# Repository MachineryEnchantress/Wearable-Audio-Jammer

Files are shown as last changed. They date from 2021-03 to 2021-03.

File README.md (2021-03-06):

# Naomi Wu's Wearable Audio Jammer
A Cyberpunk choker based on the University of Chicago, SAND Labs work:

https://sandlab.cs.uchicago.edu/jammer/

https://github.com/y-x-c/wearable-microphone-jamming

Video here:

Naomi Wu looking cyberpunk with her wearable microphone jammer on the streets of Shenzhen China. (http://www.youtube.com/watch?v=H1rozZ7ebxQ "Cyberpunk Ultrasonic Microphone Jammer")

Many thanks to JLCPCB for their sponsorship and assistance.

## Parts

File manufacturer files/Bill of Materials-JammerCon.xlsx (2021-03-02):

Designator | Comment | Value | Manufacturer Part Number 1 | Footprint | Manufacturer 1 | Quantity |  | taobao_price | Sourcing from taobao
B1, B2 | Header 9 |  |  | HDR1X9 |  | 2 |  | 0.17 | https://item.taobao.com/item.htm?spm=a1z09.2.0.0.78312e8d1CtAot&id=43937573926&_u=32085775663e15
B3, B4, B5, B6, B7, B8, B9, B10, B11 | Header 6 |  |  | HDR1X6 |  | 9 |  | 0.17 | https://item.taobao.com/item.htm?spm=a1z09.2.0.0.78312e8d1CtAot&id=43937573926&_u=32085775663e15
C2 | Cap | 22uF |  | C0805 |  | 1 |  | 0.08 | https://item.taobao.com/item.htm?spm=a1z10.3-c-s.w4002-23029579464.9.41df4181djI5tA&id=583167630909
C5 | Cap | 10uF |  | C0805 |  | 1 | https://octopart-clicks.com/click/altium?sku=490-16824-1-ND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 | 0.06 | https://item.taobao.com/item.htm?spm=a1z10.3-c-s.w4002-23029579464.9.41df4181djI5tA&id=583167630909
C7 | Cap | 100nF |  | C0603 |  | 1 | https://octopart-clicks.com/click/altium?sku=311-1341-1-ND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 | 0.03 | https://item.taobao.com/item.htm?spm=a1z10.3-c-s.w4002-23029579464.9.41df4181djI5tA&id=583167630909
C8 | Cap | 47nF |  | C0603 |  | 1 | https://octopart-clicks.com/click/altium?sku=399-7929-1-ND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 | 0.43 | https://item.taobao.com/item.htm?spm=a1z10.3-c-s.w4002-23029579464.9.41df4181djI5tA&id=583167630909
C10 | Cap | 33nF |  | C0603 |  | 1 | https://octopart-clicks.com/click/altium?sku=399-7904-1-ND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 | 0.45 | https://detail.tmall.com/item.htm?id=41231814882&cm_id=140105335569ed55e27b&abbucket=1&skuId=3984688435812
C14 | Cap | 20pF |  | C0402 |  | 1 |  | 0.025 | https://detail.tmall.com/item.htm?id=41231814882&cm_id=140105335569ed55e27b&abbucket=1&skuId=3984688435812
C15, C20 | Cap | 10uF |  | C0805 |  | 2 |  | 0.15 | https://detail.tmall.com/item.htm?id=41231814882&cm_id=140105335569ed55e27b&abbucket=1&skuId=3984688435812
C16 | Cap | 22uF |  | C0603 |  | 1 |  | 0.1 | https://detail.tmall.com/item.htm?id=41231814882&cm_id=140105335569ed55e27b&abbucket=1&skuId=3984688435812
C17, C21, C26, C36, C39, C41, C42 | Cap | 100nF |  | R0402 |  | 7 |  | 0.047 | https://detail.tmall.com/item.htm?id=41231814882&cm_id=140105335569ed55e27b&abbucket=1&skuId=3984688435812
C18 | Cap | 10nF |  | R0402 |  | 1 |  | 0.078 | https://detail.tmall.com/item.htm?id=41231814882&cm_id=140105335569ed55e27b&abbucket=1&skuId=3984688435812
C19 | Cap | 10uF |  | C0402 |  | 1 |  | 0.06 | https://detail.tmall.com/item.htm?id=41231814882&cm_id=140105335569ed55e27b&abbucket=1&skuId=3984688435812
C22, C24 | Cap | 10uF |  | C0603 |  | 2 |  | 0.12 | https://detail.tmall.com/item.htm?id=41231814882&cm_id=140105335569ed55e27b&abbucket=1&skuId=3984688435812
C23, C25 | Cap | 1uF |  | C0603 |  | 2 |  | 0.08 | https://detail.tmall.com/item.htm?id=41231814882&cm_id=140105335569ed55e27b&abbucket=1&skuId=3984688435812
C27, C28 | Cap | 220nF |  | C0603 |  | 2 |  | 0.06 | https://detail.tmall.com/item.htm?id=41231814882&cm_id=140105335569ed55e27b&abbucket=1&skuId=3984688435812
C29 | Cap | 1uF |  | R0402 |  | 1 |  | 0.06 | https://detail.tmall.com/item.htm?id=41231814882&cm_id=140105335569ed55e27b&abbucket=1&skuId=3984688435812
C34, C35 | Cap | 100nF |  | C0201 |  | 2 |  | 0.04 | https://detail.tmall.com/item.htm?id=567737110271&ns=1&abbucket=1&skuId=3788055905276
C37, C38, C43, C44 | Cap | 22pF |  | C0402 |  | 4 |  | 0.06 | https://detail.tmall.com/item.htm?id=567737110271&ns=1&abbucket=1&skuId=3788055905276
C40 | Cap | 1uF |  | C0402 |  | 1 |  | 0.06 | https://detail.tmall.com/item.htm?id=567737110271&ns=1&abbucket=1&skuId=3788055905276
D1 | MBRA340T3G |  | MBRA340T3G (https://octopart-clicks.com/click/altium?sku=MBRA340T3GOSCT-ND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) | MBRA340T3G | ON Semiconductor (https://octopart-clicks.com/click/altium?sku=MBRA340T3GOSCT-ND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) | 1 | https://octopart-clicks.com/click/altium?sku=MBRA340T3GOSCT-ND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 | 2.55 | https://detail.tmall.com/item.htm?spm=a230r.1.14.23.564d789axD7T8J&id=529444947039&ns=1&abbucket=1
D4 | MBR120VLSFT3G |  | MBR120VLSFT3G (https://octopart-clicks.com/click/altium?manufacturer=ON%20Semiconductor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) | SOD-123FL | ON Semiconductor (https://octopart-clicks.com/click/altium?manufacturer=ON%20Semiconductor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) | 1 | https://octopart-clicks.com/click/altium?manufacturer=ON%20Semiconductor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 | 3 | https://detail.tmall.com/item.htm?spm=a230r.1.14.7.21cf193buPHXgb&id=576040918117&ns=1&abbucket=1
J1 | MICRO USB MK5P |  |  | 1050170001 |  | 1 |  | 2.1 | https://detail.tmall.com/item.htm?id=21097776848&ns=1&abbucket=1&skuId=4415526175357
L1 | BMB2A0430RS2 |  | BK1608HW431-T (https://octopart-clicks.com/click/altium?sku=587-1878-1-ND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) | L0603 | Taiyo Yuden (https://octopart-clicks.com/click/altium?sku=587-1878-1-ND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) | 1 | https://octopart-clicks.com/click/altium?sku=587-1878-1-ND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 | 0.3 | https://detail.tmall.com/item.htm?id=572996827266
L3 | BLM21 |  |  | *BEADC2012X87N |  | 1 |  | 0.04 | https://item.taobao.com/item.htm?id=543681503837&ns=1&abbucket=1
L4 | Inductor | 22uH | CDRH105RNP-220NC (https://octopart-clicks.com/click/altium?sku=308-2173-1-ND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) | CDRH105RNP-220NC | Sumida (https://octopart-clicks.com/click/altium?sku=308-2173-1-ND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) | 1 | https://octopart-clicks.com/click/altium?sku=308-2173-1-ND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 | 12.5 | https://detail.tmall.com/item.htm?spm=a230r.1.14.1.379e24aaUpzAhD&id=584273759003&ns=1&abbucket=1
LED1 | RED Indicator |  | XZMDK68W-2 (https://octopart-clicks.com/click/altium?sku=1497-1174-1-ND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) | LED-0402-RED | SunLED (https://octopart-clicks.com/click/altium?sku=1497-1174-1-ND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) | 1 | https://octopart-clicks.com/click/altium?sku=1497-1174-1-ND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 | 1.06 | https://detail.tmall.com/item.htm?id=572996827266
LS1, LS2, LS3, LS4, LS5, LS6, LS7, LS8, LS9, LS10, LS11, LS12, LS13, LS14, LS15, LS16, LS17, LS18, LS19, LS20, LS21, LS22, LS23, LS24 | Ultrasonic tranducer |  |  | ULTRASONICSENSOR |  | 24 |  | 5 | https://item.taobao.com/item.htm?spm=a1z09.2.0.0.5d512e8dT8jIOL&id=574912876524&_u=32085775662157
P22 | SMT Battery connector |  | 0781710002 (https://octopart-clicks.com/click/altium?sku=WM4459CT-ND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) | CONN_MOLEX_781710002 | Molex (https://octopart-clicks.com/click/altium?sku=WM4459CT-ND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) | 1 | https://octopart-clicks.com/click/altium?sku=WM4459CT-ND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 | 1 | https://item.taobao.com/item.htm?id=589091209439&ns=1&abbucket=1
Q1, Q4 | DMG2305UX-13 |  | DMG2305UX-13 (https://octopart-clicks.com/click/altium?sku=DMG2305UX-13DICT-ND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) | SOT23-3 | Diodes (https://octopart-clicks.com/click/altium?sku=DMG2305UX-13DICT-ND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) | 2 | https://octopart-clicks.com/click/altium?sku=DMG2305UX-13DICT-ND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 | 0.8 | https://item.taobao.com/item.htm?id=566110520596&ns=1&abbucket=1
R1, R7 | Res3 | 10k |  | R0402 | Yageo (https://octopart-clicks.com/click/altium?sku=311-10KJRCT-ND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) | 2 | https://octopart-clicks.com/click/altium?sku=311-10KJRCT-ND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 | 0.033 | https://detail.tmall.com/item.htm?id=575811920221&ns=1&abbucket=1&skuId=3955476259496
R2 | Res4 | 100k |  | R0402 | Yageo (https://octopart-clicks.com/click/altium?sku=311-100KLRCT-ND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) | 1 | https://octopart-clicks.com/click/altium?sku=311-100KLRCT-ND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 | 0.0331 | https://detail.tmall.com/item.htm?id=575811920221&ns=1&abbucket=1&skuId=3955476259496
R3 | Res5 | 30k |  | R0603 | Loading... (https://octopart-clicks.com/click/altium?sku=2019-RN731JTTD6902F50TR-ND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) | 1 | https://octopart-clicks.com/click/altium?sku=2019-RN731JTTD6902F50TR-ND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 | 0.0331 | https://detail.tmall.com/item.htm?id=575811920221&ns=1&abbucket=1&skuId=3955476259496
R4 | Res6 | 143k |  | R0603 | Stackpole Electronics (https://octopart-clicks.com/click/altium?manufacturer=Stackpole%20Electronics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) | 1 | https://octopart-clicks.com/click/altium?manufacturer=Stackpole%20Electronics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 | 0.025 | https://detail.tmall.com/item.htm?id=625814257700&ns=1&abbucket=1&skuId=4438099333339
R5 | Res7 | 10k |  | R0603 | NEOHM - TE CONNECTIVITY (https://octopart-clicks.com/click/altium?manufacturer=NEOHM%20-%20TE%20CONNECTIVITY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) | 1 | https://octopart-clicks.com/click/altium?manufacturer=NEOHM%20-%20TE%20CONNECTIVITY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 | 0.03 | https://detail.tmall.com/item.htm?id=625814257700&ns=1&abbucket=1&skuId=4438099333339
R6 | Res8 | 3.09k |  | R0603 | Yageo (https://octopart-clicks.com/click/altium?sku=311-3.09KHRCT-ND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) | 1 | https://octopart-clicks.com/click/altium?sku=311-3.09KHRCT-ND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 | 0.025 | https://detail.tmall.com/item.htm?id=625814257700&ns=1&abbucket=1&skuId=4438099333339
R21, R22, R23 | Res9 | 1k |  | R0402 |  | 3 |  | 0.031 | https://detail.tmall.com/item.htm?id=575811920221&ns=1&abbucket=1&skuId=3955476259496
R24, R25, R34, R35 | Res10 | 10k |  | R0402 |  | 4 |  | 0.0331 | https://detail.tmall.com/item.htm?id=575811920221&ns=1&abbucket=1&skuId=3955476259496
R26, R27 | Res11 | 22R |  | R0402 |  | 2 |  | 0.0331 | https://detail.tmall.com/item.htm?id=575811920221&ns=1&abbucket=1&skuId=3955476259496
R28 | Res12 | 10 |  | R0402 |  | 1 |  | 0.0331 | https://detail.tmall.com/item.htm?id=575811920221&ns=1&abbucket=1&skuId=3955476259496
R29, R30 | Res13 | 10k |  | R0603 |  | 2 |  | 0.03 | https://detail.tmall.com/item.htm?id=625814257700&ns=1&abbucket=1&skuId=4438099333339
R33 | Res14 | 100k |  | R0402 |  | 1 |  | 0.0331 | https://detail.tmall.com/item.htm?id=575811920221&ns=1&abbucket=1&skuId=3955476259496
R36 | Res15 | 1k |  | R0402 |  | 1 |  | 0.031 | https://detail.tmall.com/item.htm?id=575811920221&ns=1&abbucket=1&skuId=3955476259496
R37, R38 | Res16 | 10k |  | R0201 |  | 2 |  | 0.04 | https://detail.tmall.com/item.htm?id=627633904387&cm_id=140105335569ed55e27b&abbucket=1
SW1 | TL2201EEZB |  |  | TL2201EEZB |  | 1 |  | 1.1 | https://detail.tmall.com/item.htm?spm=a230r.1.14.66.68154c60uAgV0h&id=629072861735&ns=1&abbucket=1
U1 | TPS61175PWPR |  | TPS61175PWPR (https://octopart-clicks.com/click/altium?sku=296-24013-1-ND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) | TPS61175PWPR | Texas Instruments (https://octopart-clicks.com/click/altium?sku=296-24013-1-ND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) | 1 | https://octopart-clicks.com/click/altium?sku=296-24013-1-ND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 | 2 | https://item.taobao.com/item.htm?id=612864318239&ns=1&abbucket=1
U5 | ATMEGA328P-A |  | ATMEGA328PB-AUR (https://octopart-clicks.com/click/altium?manufacturer=Microchip%20%2F%20Atmel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) | ATMEGA328P | Microchip / Atmel (https://octopart-clicks.com/click/altium?manufacturer=Microchip%20%2F%20Atmel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) | 1 | https://octopart-clicks.com/click/altium?manufacturer=Microchip%20%2F%20Atmel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 | 7.2 | https://item.taobao.com/item.htm?id=636596676424&ns=1&abbucket=1
U7 | MCP73831T-2ACI/OT |  | MCP73831T-2ACI/OT (https://octopart-clicks.com/click/altium?manufacturer=Microchip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) | SOT23-5 | Microchip (https://octopart-clicks.com/click/altium?manufacturer=Microchip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) | 1 | https://octopart-clicks.com/click/altium?manufacturer=Microchip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 | 2.5 | https://item.taobao.com/item.htm?id=634780881501&ns=1&abbucket=1
U8 | AD9833BRMZ-REEL7 |  |  | SOP50P490X110-10N |  | 1 |  | 9 | https://item.taobao.com/item.htm?id=635505137376&ns=1&abbucket=1
U9 | PAM8403DR |  |  | SOIC127P605X175-16N |  | 1 |  | 0.85 | https://item.taobao.com/item.htm?id=608059829639&ns=1&abbucket=1
U11 | ATMEGA16U2-MU |  |  | *QFN50P500X500X100-33N |  | 1 |  | 13 | https://item.taobao.com/item.htm?id=622633930047&ns=1&abbucket=1
Y1 | 25MHz |  | ECS-3951M-250-BN-TR (https://octopart-clicks.com/click/altium?sku=XC321CT-ND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) | OSC_ECS-3951M-250-BN-TR | ECS International (https://octopart-clicks.com/click/altium?sku=XC321CT-ND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) | 1 | https://octopart-clicks.com/click/altium?sku=XC321CT-ND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 | 1.5 | https://item.taobao.com/item.htm?id=596798388613&ali_trackid=1_60a99f19a8de875dff8d5a230e91020d
Y3, Y4 | 16MHz | 16MHz |  | BT-XTAL_2016_N |  | 2 |  | 1.7 | https://item.taobao.com/item.htm?id=596798388613&ali_trackid=1_60a99f19a8de875dff8d5a230e91020d
Z3, Z4 | VARISTOR_0603 |  |  | *R0603 |  | 2 |  | 1.1 | https://detail.tmall.com/item.htm?spm=a230r.1.14.8.2f1137ddH6zNkv&id=629202685810&ns=1&abbucket=1
D5, D6 | Do not place |  |  |  | ON Semiconductor / Fairchild (https://octopart-clicks.com/click/altium?manufacturer=ON%20Semiconductor%20%2F%20Fairchild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) | 2
P23 | Do not place |  |  | HDR1X2 |  | 1
P24 | Do not place |  |  | HDR1X2 |  | 1
P25, P26 | Do not place |  |  | TC2030-MCP |  | 2

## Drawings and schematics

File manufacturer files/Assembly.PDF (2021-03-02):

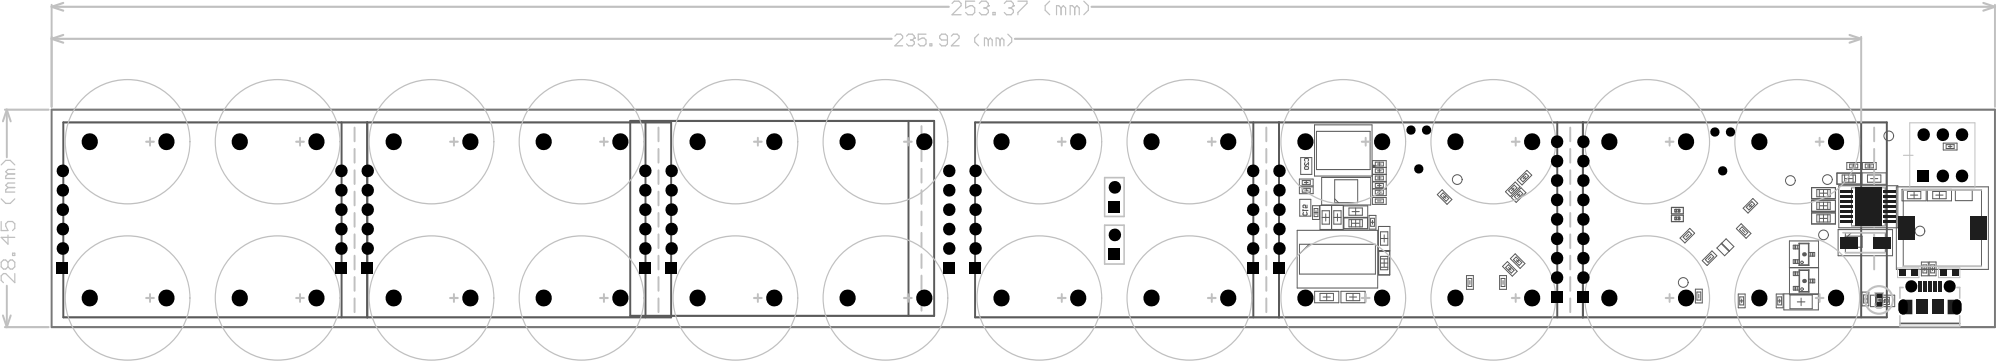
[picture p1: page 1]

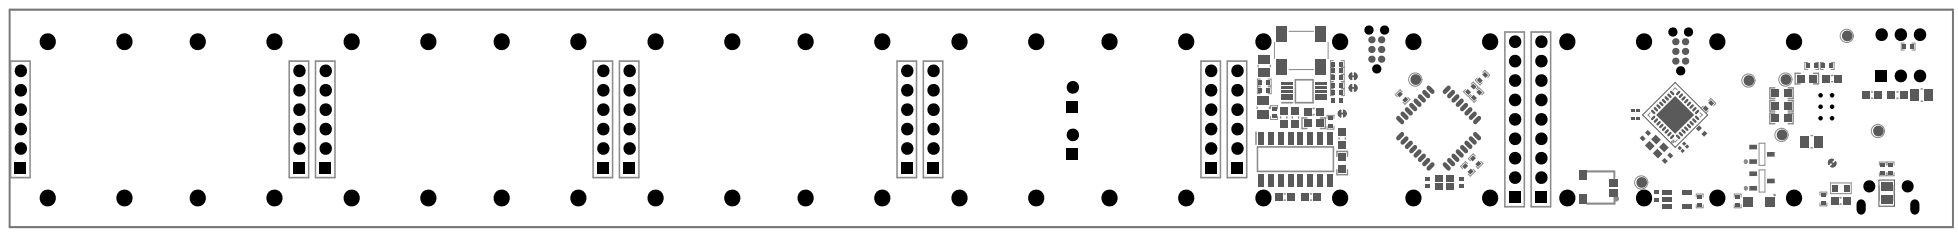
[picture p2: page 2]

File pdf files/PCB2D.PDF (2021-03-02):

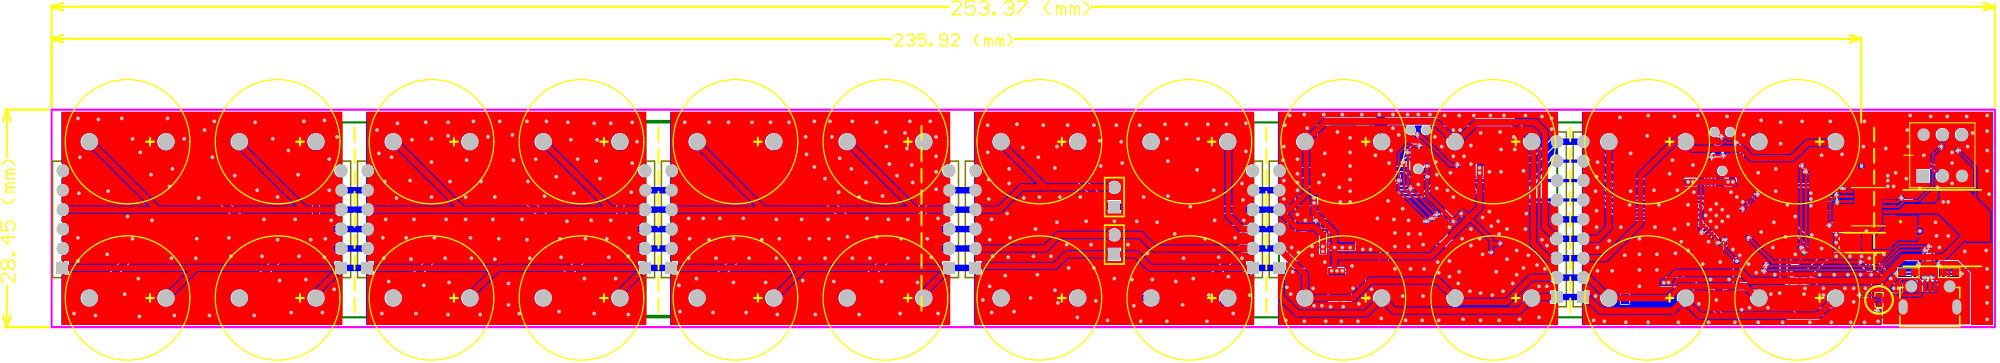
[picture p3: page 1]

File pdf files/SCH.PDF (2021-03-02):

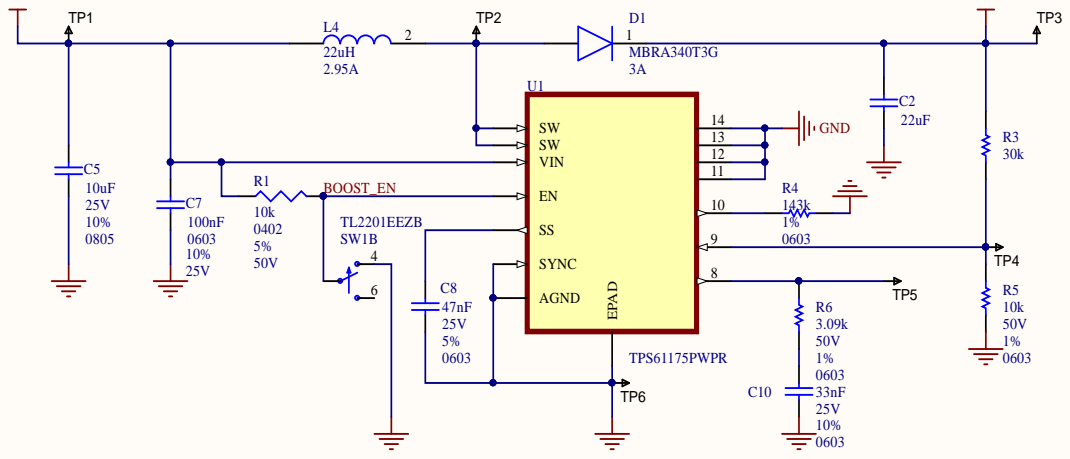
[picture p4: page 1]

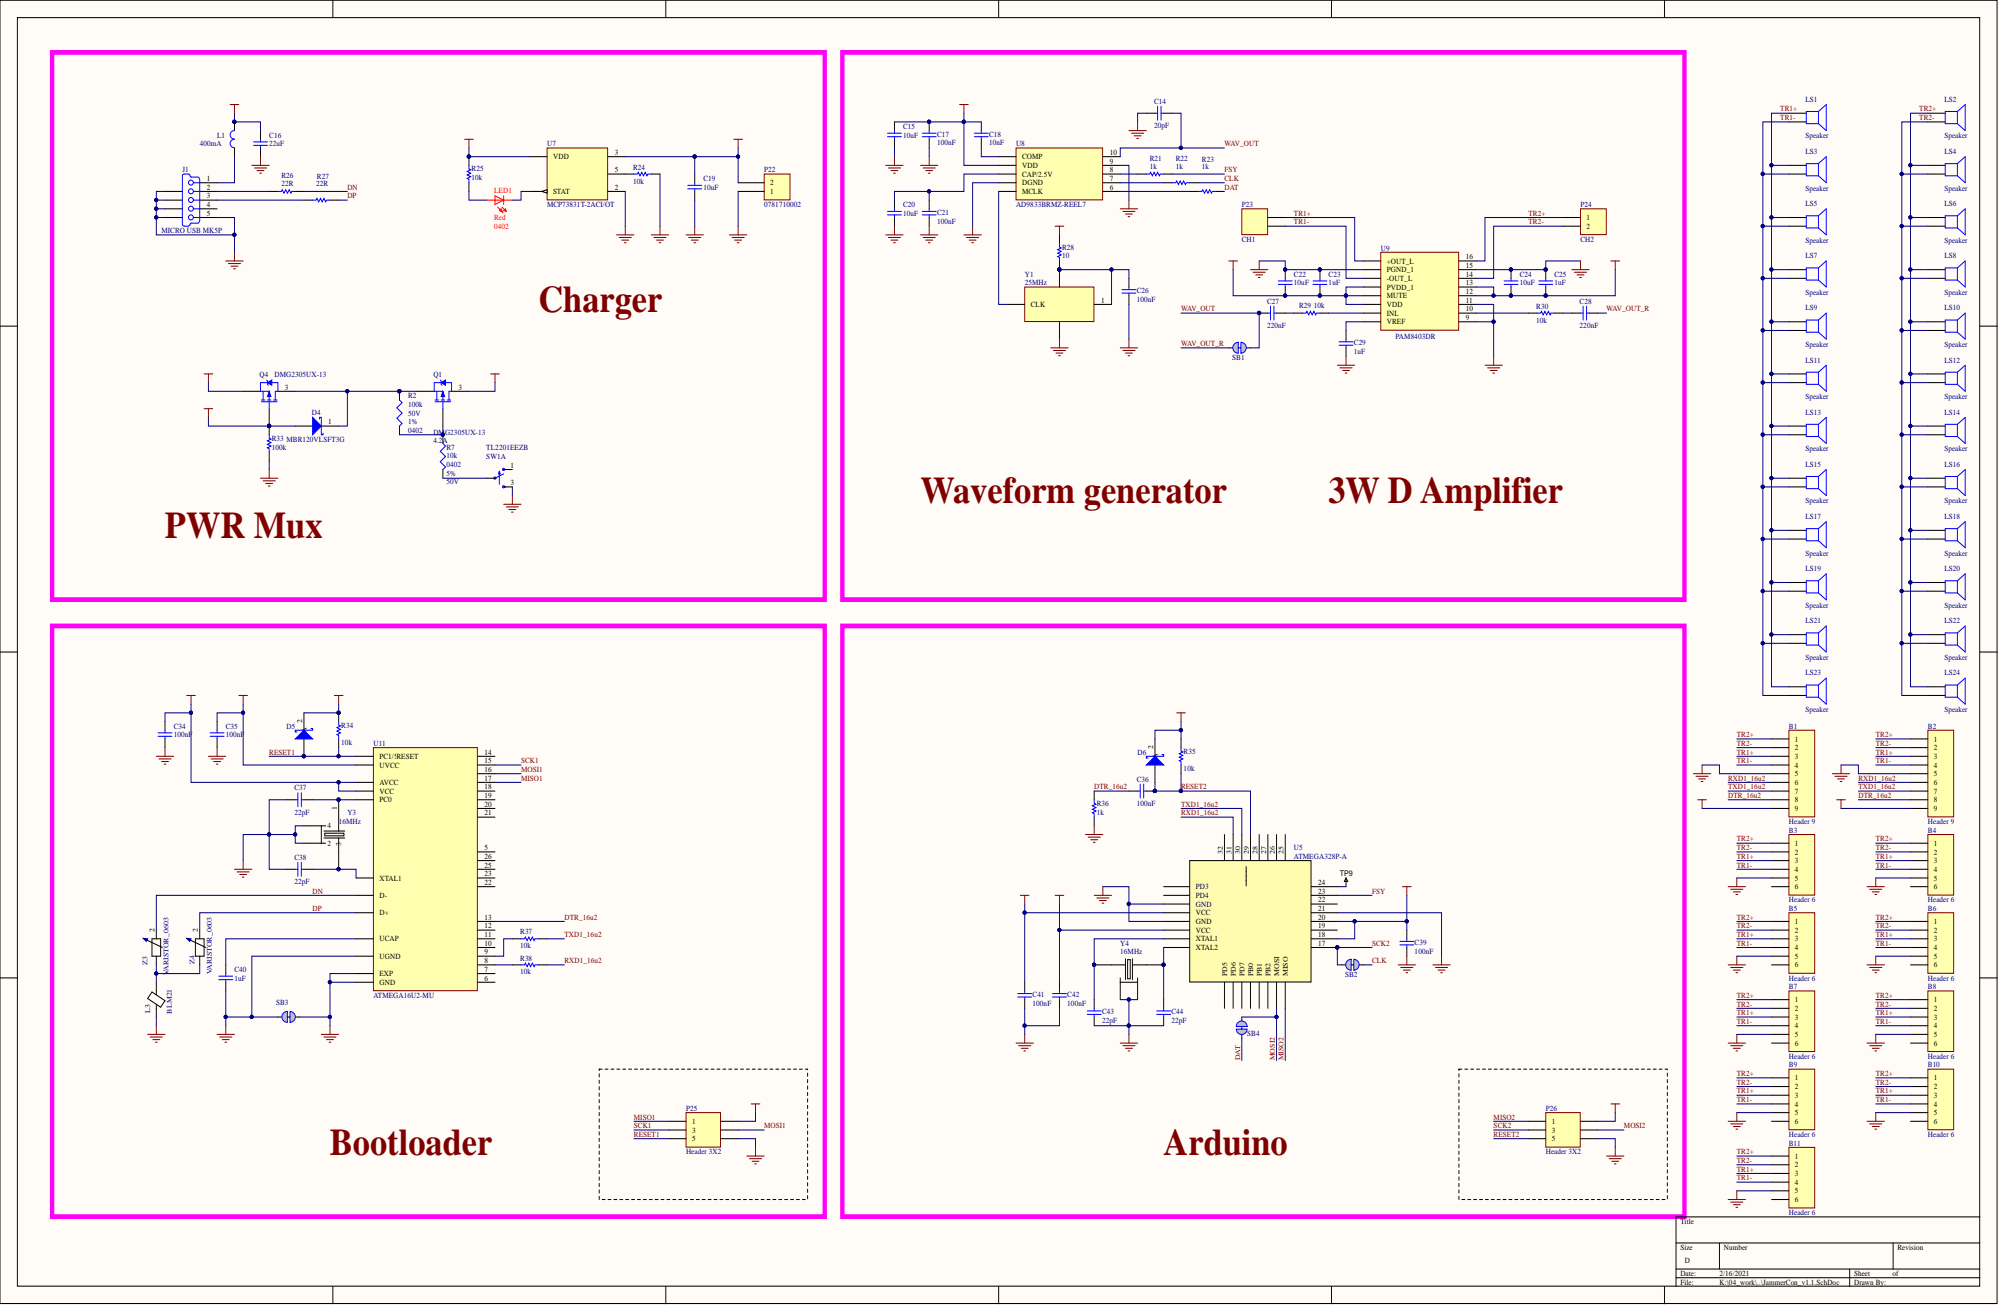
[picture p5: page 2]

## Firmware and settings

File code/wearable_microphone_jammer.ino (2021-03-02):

/*
    wearable microphone jammer
    --------
    This is the code for 
    Circuit buildup and wiring explanation added in comments by Steven Nagels and Shan-Yuan Teng.
   
    HARDWARE
    --------
    - Pro Trinket 5V board. https://www.adafruit.com/product/2000
    - AD9833 Waveform Module https://www.amazon.com/gp/product/B076LF3LFC
   
    CONNECTION
    --------
    AD9833 PCB to Pro Trinket board:
    DAT --> pin 11 (MOSI) [note: pin 12 is MISO]
    CLK --> pin 13 (SCK)
    FSY --> pin A0 (AD9833 SS)
    CS --> pin A1 (MCP41010i SS)
    
    AD9833 PCB OVERVIEW
    --------
    PCB has following INPUTS (in order): CS, DAT, CLK, FSY, GND, VCC
                  and OUTPUTS (in order): GND, PGA, (footprint for SMA connector), VOUT, GND

    LOOKING AT PCB WITH INPUTS FACING YOU: left side = PGA, right side = waveform generator

    (left side)
    PGA stands for Programmable Gain Amplifier and is constructed of a MCP41010i digital potentiometer (addressed via SPI)
    and an AD8051 high speed operational amplifier. By changing the MCP41010i resistance value, you set the amplifier's gain.
    The SMA connector footprint also connects to the PGA output.

    MCP41010i is on the SPI bus, thus has a shared connection to DAT and CLK with the AD9833. Its chip select is the CS input.

    MCP41010i datasheet: http://ww1.microchip.com/downloads/en/devicedoc/11195c.pdf
    AD8051 datasheet: https://www.analog.com/media/en/technical-documentation/data-sheets/AD8051_8052_8054.pdf

    (right side)
    A large 25 MHz xtal on top half of board. It determines the reference frequency used in the code below. AD9833 situated
    on bottom half of board. This part is completely controlled via SPI.

    AD9833 is on the SPI bus, thus has a shared connection to DAT and CLK with the MCP41010i. Its chip select is the FSY input.

    AD9833 datasheet: https://www.analog.com/media/en/technical-documentation/data-sheets/AD9833.pdf
*/

/*
   ApplySignal.ino
   2018 WLWilliams

   This sketch demonstrates the basic use of the AD9833 DDS module library.
   Using the ApplySignal to generate and/or change the signal.

   This program is free software: you can redistribute it and/or modify it under
   the terms of the GNU General Public License as published by the Free Software Foundation,
   either version 3 of the License, or (at your option) any later version.
   This program is distributed in the hope that it will be useful, but WITHOUT ANY WARRANTY;
   without even the implied warranty of MERCHANTABILITY or FITNESS FOR A PARTICULAR PURPOSE.
   See the GNU General Public License for more details. You should have received a copy of
   the GNU General Public License along with this program.
   If not, see <http://www.gnu.org/licenses/>.

   This example code is in the public domain.

   Library code found at: https://github.com/Billwilliams1952/AD9833-Library-Arduino
*/

#include "AD9833.h"

#define FNC_PIN A0
#define SEL_PIN A1

int gen_freq = 25000;

int RXLED = 3;  // The RX LED has a defined Arduino pin

//--------------- Create an AD9833 object ----------------
// Note, SCK and MOSI must be connected to CLK and DAT pins on the AD9833 for SPI
AD9833 gen(FNC_PIN);       // Defaults to 25MHz internal reference frequency

void setup() {
//  start gen
  delay(500);
  gen.Begin();
  pinMode(SEL_PIN, OUTPUT);
  //set gen to SINE
  gen.ApplySignal(SINE_WAVE, REG0, gen_freq);
  //start gens
  gen.EnableOutput(true);
  //put both PGAs at max output
//  MCP41010Write(255, SEL_PIN);
  SPI.setDataMode(SPI_MODE2);

//  pinMode(RXLED, OUTPUT);
}

void loop() {
  gen.ApplySignal(SINE_WAVE, REG0, random(24000, 26000));
//  MCP41010Write(255, SEL_PIN);/
}

//  function below adapted from http://henrysbench.capnfatz.com/henrys-bench/arduino-output-devices/mcp41010-digital-potentiometer-arduino-user-manual/
//  8bit value to write --> 256 levels --> value 0 to 255
void MCP41010Write(byte value, int CS)
{
  SPI.setDataMode(SPI_MODE0);
  // Note that the integer vale passed to this subroutine
  // is cast to a byte
  digitalWrite(CS, LOW);
  SPI.transfer(B00010001); // This tells the chip to set the pot
  SPI.transfer(value);     // This tells it the pot position
  digitalWrite(CS, HIGH);
}
